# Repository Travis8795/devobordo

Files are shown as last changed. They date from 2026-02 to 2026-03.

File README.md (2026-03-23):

# devobordo

devobordo is a custom RP2040 development board designed from scratch in KiCad.

The goal of this project was try and work on the RP2040 architecture, power design, PCB layout, and manufacturability constraints (JLCPCB).

This board provides a minimal but fully functional RP2040 platform with clean power routing, proper decoupling, USB interface, full GPIO breakout for experimentation, and battery capability.

| front | back |
| :---: | :---: |
|  |  |

## Features

- RP2040 (Dual-core ARM Cortex-M0+ @ 133MHz)
- USB-C and battery power input
- MCP1700 3.3V linear regulator
- External QSPI Flash
- 12 MHz crystal oscillator
- SWD programming/debug header
- Dual LED indicators:
  - Power LED (3V3)
  - GPIO25 activity LED
- Full GPIO breakout headers
- 2-layer PCB optimized for low impedance power routing

## Power Architecture
*DO NOT CHARGE THE BATTERY WITH THE BOARD, CHARGE IT WITH AN EXTERNAL CHARGER*
- USB 5V input
- Reverse protection diode
- MCP1700 3.3V LDO regulator
- Wide 3V3 power backbone (low impedance design)
- Ground plane with via stitching
- Proper decoupling for:
  - 3V3 rail
  - 1V1 core regulator
  - QSPI flash
  - Crystal oscillator

## Designed With

- KiCad 9
- JLCPCB assembly constraints
- RP2040 datasheet reference design
- Blueprint Hackclub devboard guide

## Manufacturing

- 2-layer PCB
- 1oz copper
- JLCPCB assembly
- Standard component footprints (0603, 0402)

## What I Learned

- RP2040 power domain separation (3V3 vs 1V1)
- Decoupling capacitor placement strategy
- Thermal relief tuning
- USB differential routing basics
- DRC debugging
- Dealing with ground isolated islands

---

| front layer | back layer | schema |
| :---: | :---: | :---: |
|  |  |  |

## BOM table

| Description | Value | Footprint | LCSC Part # | Quantity | Notes |
| --- | --- | --- | --- | --- | --- |
| Microcontroller | RP2040 | QFN-56 | C2040 | 1 | Main MCU |
| QSPI Flash | W25Q16JV | SOIC-8 | C97521 | 1 | External flash |
| LDO Regulator | MCP1700-3302 | SOT-23 | C62354 | 1 | 3.3V regulator |
| Crystal | 12MHz | 3225 | C9002 | 1 | Main clock |
| LED | Red 0603 | 0603 | C2286 | 2 | Power indicator, and GPIO25|
| Resistor | 1kΩ | 0402 | C21190 | 2 | LED current limit |
| Resistor | 27Ω | 0402 | C21190 | 2 | USB D+/D- |
| Resistor | 5.1KΩ | 0402 | C21190 | 2 | CC pull down |
| Ceramic Capacitor | 100nF | 0402 | C14663 | 11 | Decoupling |
| Ceramic Capacitor | 10uF | 0603 | C19702 | 2 | Bulk filtering |
| Ceramic Capacitor | 1uF | 0402 | C15849 | 2 | Core regulator |
| Ceramic Capacitor | 33pF | 0402 | C1562 | 2 | crystal filtering |
| Push Button | SW_Push | SW_Push_SPST_NO_Alps_SKRK  | C341730 | 1 | Bootloder |
| Diod | 1N4148WT | D_SOD-123  | C78089 | 2 | Reverse protection |
| USB_C receptacle | USB_C_Receptacle_USB2.0_14P | USB_C_Receptacle_HRO_TYPE-C-31-M-12  | C165948 | 1 | USB connection |

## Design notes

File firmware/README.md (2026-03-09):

The board is compatible with the official Pico SDK.
[Setup guide](https://datasheets.raspberrypi.com/pico/getting-started-with-pico.pdf)

| Function | GPIO |
| --- | --- |
| Status LED | GPIO25 |
| USB | GPIO24 / GPIO25 internal |
| SWD Debug  | SWCLK / SWDIO |
| UART | GPIO0 / GPIO1 |
| I2C | GPIO4 / GPIO5 |
| SPI | GPIO16–19 |

for the [latest update](https://micropython.org/download/RPI_PICO/)

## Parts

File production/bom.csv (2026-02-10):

Designator | Footprint | Quantity | Value | LCSC Part #
C1, C10, C11, C17, C2, C3, C4, C5, C6, C7, C8 | 0402 | 11 | 0.1uF
C12, C9 | 0402 | 2 | 1uF
C13, C14 | 0603 | 2 | 10uF
C15, C16 | 0402 | 2 | 33pF
D1, D2 | D_SOD-123 | 2 | 1N4148WT
D3, D4 | 0603 | 2 | LED
J1 | USB_C_Receptacle_HRO_TYPE-C-31-M-12 | 1 | USB_C_Receptacle_USB2.0_14P
J2 | JST_PH_B2B-PH-K_1x02_P2.00mm_Vertical | 1 | Conn_01x02
J3, J5 | PinHeader_1x20_P2.54mm_Vertical | 2 | Conn_01x20
J4 | PinHeader_1x03_P2.54mm_Vertical | 1 | Conn_01x03
R1, R2 | 0402 | 2 | 5.1K
R3, R4 | 0402 | 2 | 27
R5, R6, R8, R9 | 0402 | 4 | 1K
R7 | 0402 | 1 | 10K
SW1 | SW_Push_SPST_NO_Alps_SKRK | 1 | SW_Push
U1 | QFN-56-1EP_7x7mm_P0.4mm_EP3.2x3.2mm | 1 | RP2040
U2 | SOT-23 | 1 | MCP1700x-330xxTT
U3 | Winbond_USON-8-1EP_3x2mm_P0.5mm_EP0.2x1.6mm | 1 | W25Q16JVZPIQ TR
Y1 | Crystal_SMD_3225-4Pin_3.2x2.5mm | 1 | 12 MHz

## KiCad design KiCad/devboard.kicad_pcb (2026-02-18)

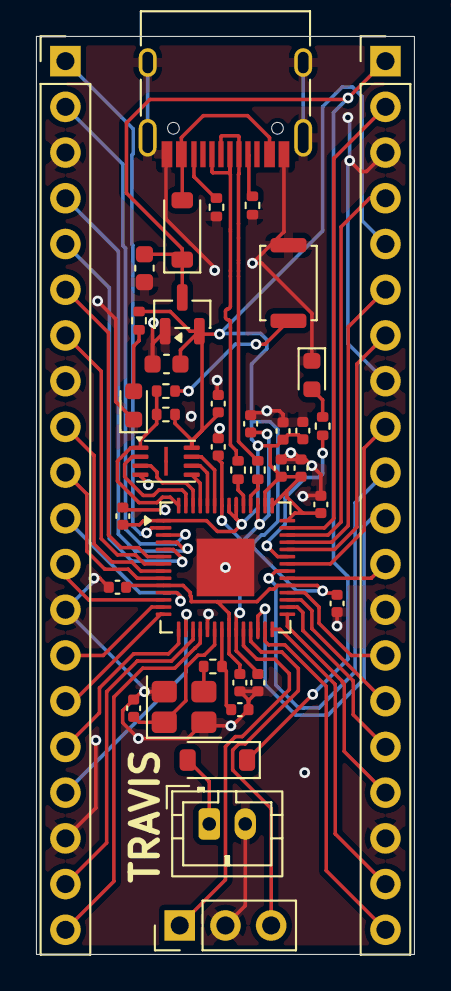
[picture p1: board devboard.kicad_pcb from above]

Board: 2 copper layers, 21.0 x 51.0 mm, 40 parts (0 on the bottom side), 57 nets.

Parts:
C1, C2, C3, C4, C5, C6, C7, C8, C10, C11, C17: 0.1uF; C_0402_1005Metric
C9, C12: 1uF; C_0402_1005Metric
C13, C14: 10uF; C_0603_1608Metric
C15, C16: 33pF; C_0402_1005Metric
D1, D2: 1N4148WT; D_SOD-123
D3, D4: LED; LED_0603_1608Metric
J1: USB_C_Receptacle_USB2.0_14P; USB_C_Receptacle_HRO_TYPE-C-31-M-12
J2: Conn_01x02; JST_PH_B2B-PH-K_1x02_P2.00mm_Vertical
J3, J5: Conn_01x20; PinHeader_1x20_P2.54mm_Vertical
J4: Conn_01x03; PinHeader_1x03_P2.54mm_Vertical
R1, R2: 5.1K; R_0402_1005Metric
R3, R4: 27; R_0402_1005Metric
R5, R6, R8, R9: 1K; R_0402_1005Metric
R7: 10K; R_0402_1005Metric
SW1: SW_Push; SW_Push_SPST_NO_Alps_SKRK
U1: RP2040; QFN-56-1EP_7x7mm_P0.4mm_EP3.2x3.2mm
U2: MCP1700x-330xxTT; SOT-23
U3: W25Q16JVZPIQ TR; Winbond_USON-8-1EP_3x2mm_P0.5mm_EP0.2x1.6mm
Y1: 12 MHz; Crystal_SMD_3225-4Pin_3.2x2.5mm

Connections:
+1V1: C10.1, C11.1, C12.1, U1.23 (DVDD), U1.45 (VREG_VOUT), U1.50 (DVDD)
+3V3: C1.1, C2.1, C3.1, C4.1, C5.1, C6.1, C7.1, C8.1, C9.1, C14.1, C17.1, J5.5, R7.1, R8.1, U1.1 (IOVDD), U1.10 (IOVDD), U1.22 (IOVDD), U1.33 (IOVDD), U1.42 (IOVDD), U1.43 (ADC_AVDD), U1.44 (VREG_VIN), U1.48 (USB_VDD), U1.49 (IOVDD), U2.2 (VO), U3.8 (VCC)
GND: C1.2, C2.2, C3.2, C4.2, C5.2, C6.2, C7.2, C8.2, C9.2, C10.2, C11.2, C12.2, C13.2, C14.2, C15.1, C16.1, C17.2, D3.1 (K), D4.1 (K), J1.A1 (GND), J1.A12 (GND), J1.B1 (GND), J1.B12 (GND), J1.S1 (SHIELD), J2.2, J3.3, J3.8, J3.13, J3.18, J4.2, J5.3, J5.8, J5.13, J5.18, R1.2, R2.2, SW1.1, U1.19 (TESTEN), U1.57 (GND), U2.1 (GND), U3.4 (GND), Y1.2 (G), Y1.4 (G)
GPIO0: J3.1, U1.2 (GPIO0)
GPIO1: J3.2, U1.3 (GPIO1)
GPIO2: J3.4, U1.4 (GPIO2)
GPIO3: J3.5, U1.5 (GPIO3)
GPIO4: J3.6, U1.6 (GPIO4)
GPIO5: J3.7, U1.7 (GPIO5)
GPIO6: J3.9, U1.8 (GPIO6)
GPIO7: J3.10, U1.9 (GPIO7)
GPIO8: J3.11, U1.11 (GPIO8)
GPIO9: J3.12, U1.12 (GPIO9)
GPIO10: J3.14, U1.13 (GPIO10)
GPIO11: J3.15, U1.14 (GPIO11)
GPIO12: J3.16, U1.15 (GPIO12)
GPIO13: J3.17, U1.16 (GPIO13)
GPIO14: J3.19, U1.17 (GPIO14)
GPIO15: J3.20, U1.18 (GPIO15)
GPIO16: J5.20, U1.27 (GPIO16)
GPIO17: J5.19, U1.28 (GPIO17)
GPIO18: J5.17, U1.29 (GPIO18)
GPIO19: J5.16, U1.30 (GPIO19)
GPIO20: J5.15, U1.31 (GPIO20)
GPIO21: J5.14, U1.32 (GPIO21)
GPIO22: J5.12, U1.34 (GPIO22)
GPIO23: J5.10, U1.35 (GPIO23)
GPIO24: J5.9, U1.36 (GPIO24)
GPIO25: R9.1, U1.37 (GPIO25)
GPIO26/ADC0: J5.7, U1.38 (GPIO26/ADC0)
GPIO27/ADC1: J5.6, U1.39 (GPIO27/ADC1)
GPIO28/ADC2: J5.4, U1.40 (GPIO28/ADC2)
GPIO29/ADC3: J5.2, U1.41 (GPIO29/ADC3)
unnamed: D1.2 (A), J1.A4 (VBUS), J1.A9 (VBUS), J1.B4 (VBUS), J1.B9 (VBUS)
unnamed: D2.2 (A), J2.1
unnamed: D3.2 (A), R8.2
unnamed: D4.2 (A), R9.2
unnamed: J1.A5 (CC1), R1.1
unnamed: J1.B5 (CC2), R2.1
unnamed: R5.1, Y1.3
unnamed: R6.1, SW1.2
unnamed: R3.2, U1.46 (USB_DM)
unnamed: R4.2, U1.47 (USB_DP)
QSPI_SCLK: U1.52 (QSPI_SCLK), U3.6 (CLK)
QSPI_SD0: U1.53 (QSPI_SD0), U3.5 (DI/IO_{0})
QSPI_SD1: U1.55 (QSPI_SD1), U3.2 (DO/IO_{1})
QSPI_SD2: U1.54 (QSPI_SD2), U3.3 (~WP/IO_{2})
QSPI_SD3: U1.51 (QSPI_SD3), U3.7 (~HOLD/~RESET/IO_{3})
QSPI_SS: R6.2, R7.2, U1.56 (~QSPI_SS), U3.1 (~CS)
RUN: J5.11, U1.26 (RUN)
SWCLK: J4.1, U1.24 (SWCLK)
SWDIO: J4.3, U1.25 (SWDIO)
USB_D+: J1.A6 (D+), J1.B6 (D+), R4.1
USB_D-: J1.A7 (D-), J1.B7 (D-), R3.1
VBUS: C13.1, D1.1 (K), D2.1 (K), J5.1, U2.3 (VI)
XIN: C15.2, U1.20 (XIN), Y1.1
XOUT: C16.2, R5.2, U1.21 (XOUT)

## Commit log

2026-02-10 Enhance README with project details and features
    Expanded the README to include detailed features, power architecture, PCB design goals, manufacturing details, and lessons learned from the project.
2026-02-10 Update README with board images and schema
    Added images of the front and back layers of the board along with their schema.
2026-02-10 Revise README with project goals and design updates
    Updated project goals and added battery capability to the board description. Revised PCB design goals and added additional design considerations.
2026-02-18 reorganizing files
    [devboard.kicad_pcb, devboard.kicad_sch]
2026-03-09 Add README with board compatibility and GPIO info
2026-03-09 Update README with link to latest MicroPython update
    Add link to latest MicroPython update for RPI PICO.
2026-03-23 Add battery charging warning to README
    Added warning about charging the battery with the board.
